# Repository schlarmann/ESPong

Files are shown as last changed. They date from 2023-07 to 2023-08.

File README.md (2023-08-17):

# ESPong
PCB / Code for the ESP8266 Pong game. Based on the ESP Channel3 library

## File structure
 - pongCard: KiCad project for the pcb. Currently in Version 3
 - channel3Pong: Source code for ESPong itself. Code needs to refactored, it was written with / for cnlohr's SDK and then simply ported over to the arduino library.
 - channel3Image: Displays a static Image (Makerspace Minden logo). Comes with a converter script to convert pngs to header files.
 - channel3EtchASketch: Simple Etch-A-Sketch implementation for the pongCard. Demo board has rotating potentiometers instead of linear ones. Results are still "dotty" and there is no reset button to clear the screen

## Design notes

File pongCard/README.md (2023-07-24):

# Pong card
PCB for ESPong3D

## BOM
| Reference | Qty | Value | Link | 
|---|-----|---|---|
| BT1, BT2 | 2 | AAA | https://www.lcsc.com/product-detail/Battery-Connectors_MYOUNG-BH-AAA-A1AJ001_C5290189.html |
| C1, C3, C8 | 3 | 100u | https://www.lcsc.com/product-detail/Multilayer-Ceramic-Capacitors-MLCC-SMD-SMT_Samsung-Electro-Mechanics-CL31A107MQHNNNE_C15008.html |
| C4, C9, C2 | 2 | 100n | https://www.lcsc.com/product-detail/Multilayer-Ceramic-Capacitors-MLCC-SMD-SMT_Walsin-Tech-Corp-0603B104K250CT_C83054.html |
| C5, C6 | 2 | 22p |  |
| C7 | 1 | 100p |  |
| D1 | 1 | 1N5819 | https://www.lcsc.com/product-detail/Schottky-Barrier-Diodes-SBD_HXY-MOSFET-1N5819W_C5451628.html |
| J1 | 1 | USB_B_Micro | https://www.lcsc.com/product-detail/USB-Connectors_SHOU-HAN-MicroXNJ_C404969.html |
| L1 | 1 | 47µ | https://www.lcsc.com/product-detail/Inductors-SMD_Sunlord-AWL3225FP470MTF_C2846230.html |
| R1, R2, R3, R4, R5 | 5 | 22k | https://www.lcsc.com/product-detail/Chip-Resistor-Surface-Mount_RALEC-RTT03223JTP_C103426.html |
| R6 | 1 | 47R |  |
| RV1, RV2 | 2 | 10k // 100k | https://www.lcsc.com/product-detail/Variable-Resistors-Potentiometers_ALPSALPINE-RS30H11AA009_C470610.html(or: https://www.pollin.de/p/schieberegler-30ld1c-b-cap5-100k-240836) |
| SW1 | 1 | SW_SPDT_COM | https://www.lcsc.com/product-detail/Slide-Switches_SHOU-HAN-MSK12C02-HB_C431541.html |
| U2 | 1 | HT7533-1-SOT89 | https://lcsc.com/product-detail/Linear-Voltage-Regulators-LDO_KEXIN-HT7533_C499633.html |
| U3 | 1 | ESP-12E | https://www.lcsc.com/product-detail/WiFi-Modules_Ai-Thinker-ESP-12F-ESP8266MOD_C82891.html |
| U4 | 1 | QX2303L33E | https://www.lcsc.com/product-detail/DC-DC-Converters_QX-Micro-Devices-QX2303L33E_C236071.html |

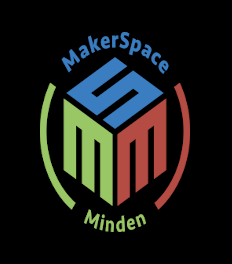
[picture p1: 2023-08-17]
channel3Image/convert/image.png

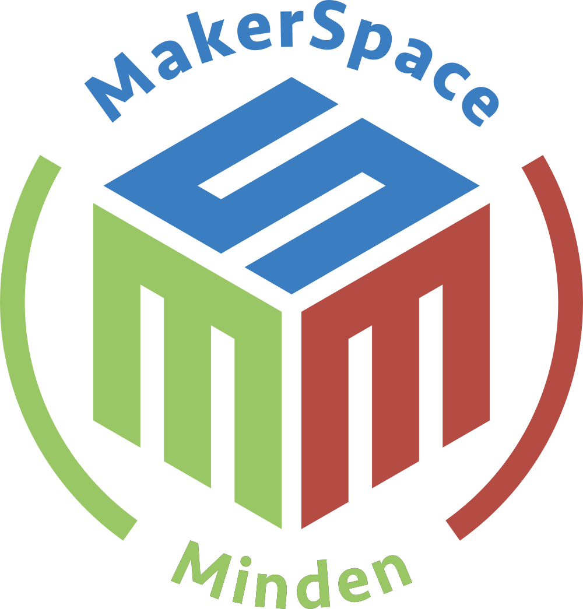
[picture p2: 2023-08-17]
channel3Image/convert/image_raw.png

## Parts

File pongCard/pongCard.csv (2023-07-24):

# | Reference | Qty | Value | Footprint | DNP
1 | BT1, BT2 | 2 | AAA | pongCard:BatteryHolder_AAA_MYOUNG
2 | C1, C3, C8 | 3 | 100u | Capacitor_SMD:C_1206_3216Metric_Pad1.33x1.80mm_HandSolder
3 | C2 | 1 | 100nF | Capacitor_SMD:C_0603_1608Metric_Pad1.08x0.95mm_HandSolder
4 | C4, C9 | 2 | 100n | Capacitor_SMD:C_0603_1608Metric_Pad1.08x0.95mm_HandSolder
5 | C5, C6 | 2 | 22p | Capacitor_SMD:C_0603_1608Metric_Pad1.08x0.95mm_HandSolder
6 | C7 | 1 | 100p | Capacitor_SMD:C_0603_1608Metric_Pad1.08x0.95mm_HandSolder
7 | D1 | 1 | 1N5819 | Diode_SMD:D_SOD-123
8 | J1 | 1 | USB_B_Micro | Connector_USB:USB_Micro-B_Molex-105017-0001
9 | J2, J3 | 2 | Conn_02x04_Odd_Even | pongCard:protoPins2x4
10 | JP1, JP2, JP3, JP4 | 4 | Jumper_2_Open | Jumper:SolderJumper-2_P1.3mm_Open_RoundedPad1.0x1.5mm
11 | L1 | 1 | 47µ | Inductor_SMD:L_1210_3225Metric_Pad1.42x2.65mm_HandSolder
12 | R1, R2, R3, R4, R5 | 5 | 22k | Resistor_SMD:R_0603_1608Metric_Pad0.98x0.95mm_HandSolder
13 | R6 | 1 | 47R | Resistor_SMD:R_0603_1608Metric_Pad0.98x0.95mm_HandSolder
14 | RV1, RV2 | 2 | 10k // 100k | pongCard:linearPotentiometer
15 | SW1 | 1 | SW_SPDT_COM | pongCard:SW_SPDT_PCM12_COM
16 | U1 | 1 | ESP-01v090 | pongCard:ESP-01
17 | U2 | 1 | HT75xx-1-SOT89 | Package_TO_SOT_SMD:SOT-89-3_Handsoldering
18 | U3 | 1 | ESP-12E | ESP8266:ESP-12E
19 | U4 | 1 | QX2303L33E | Package_TO_SOT_SMD:SOT-89-3_Handsoldering

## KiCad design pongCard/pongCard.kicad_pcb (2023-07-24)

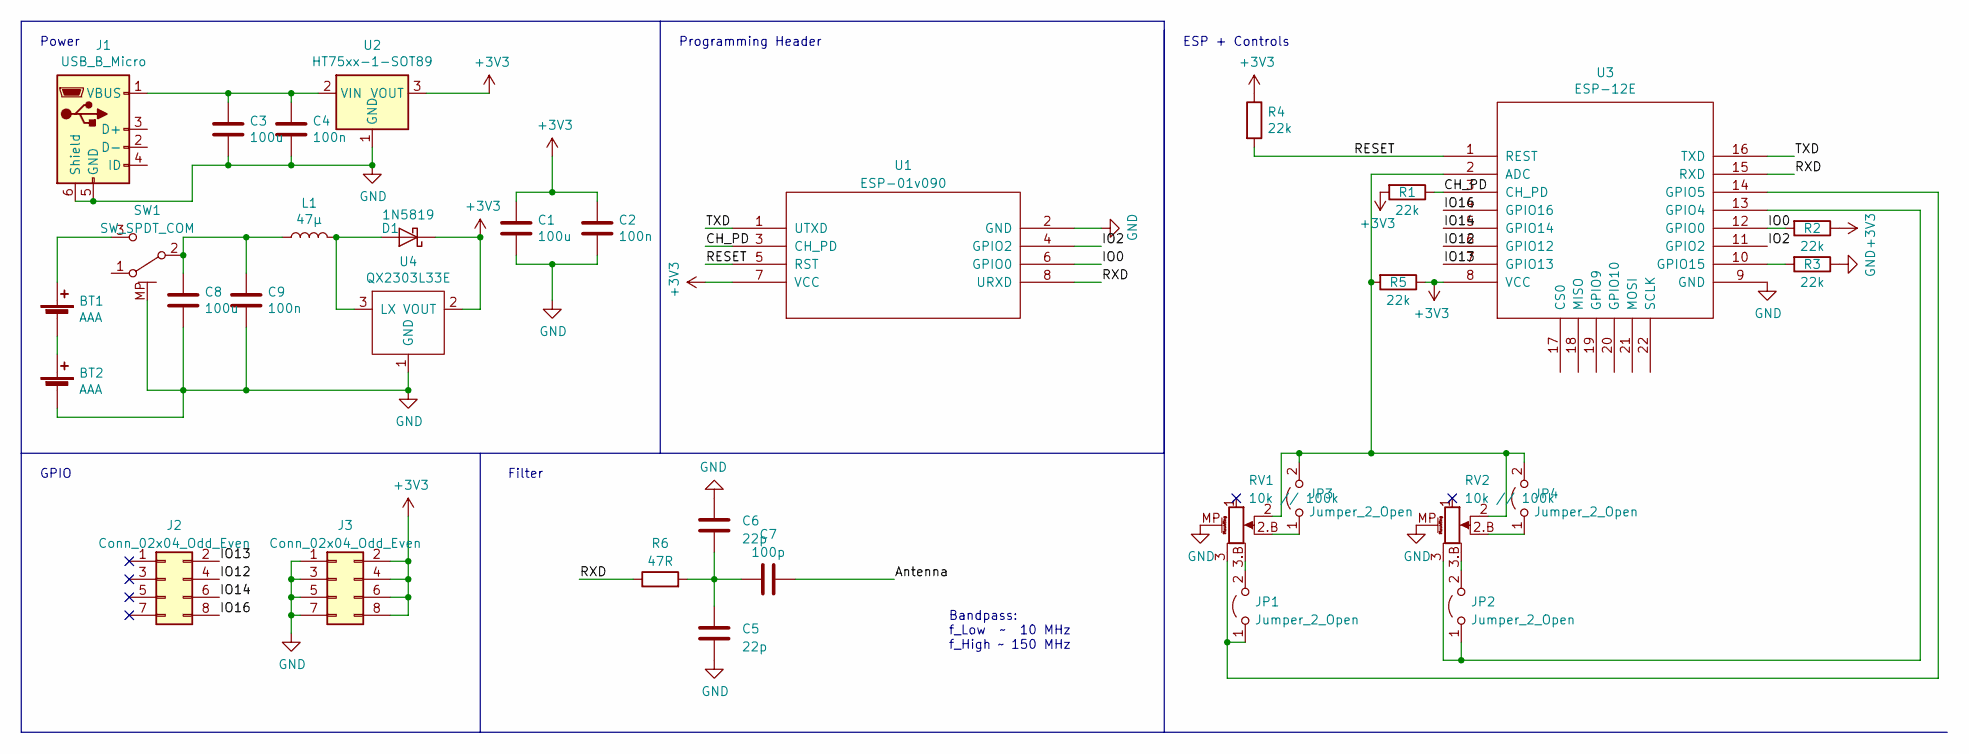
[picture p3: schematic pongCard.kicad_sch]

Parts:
BT1, BT2: AAA; BatteryHolder_AAA_MYOUNG
C1, C3, C8: 100u; C_1206_3216Metric_Pad1.33x1.80mm_HandSolder
C2, C4, C9: 100n; C_0603_1608Metric_Pad1.08x0.95mm_HandSolder
C5, C6: 22p; C_0603_1608Metric_Pad1.08x0.95mm_HandSolder
C7: 100p; C_0603_1608Metric_Pad1.08x0.95mm_HandSolder
D1: 1N5819; D_SOD-123
J1: USB_B_Micro; USB_Micro-B_Molex-105017-0001
J2, J3: Conn_02x04_Odd_Even; protoPins2x4
JP1, JP2, JP3, JP4: Jumper_2_Open; SolderJumper-2_P1.3mm_Open_RoundedPad1.0x1.5mm
L1: 47µ; L_1210_3225Metric_Pad1.42x2.65mm_HandSolder
R1, R2, R3, R4, R5: 22k; R_0603_1608Metric_Pad0.98x0.95mm_HandSolder
R6: 47R; R_0603_1608Metric_Pad0.98x0.95mm_HandSolder
RV1, RV2: 10k // 100k; linearPotentiometer
SW1: SW_SPDT_COM; SW_SPDT_PCM12_COM
U1: ESP-01v090; ESP-01
U2: HT75xx-1-SOT89; SOT-89-3_Handsoldering
U3: ESP-12E
U4: QX2303L33E; SOT-89-3_Handsoldering

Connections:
+3V3: C1.1, C2.1, D1.1 (K), J3.2, J3.4, J3.6, J3.8, R1.2, R2.1, R4.1, R5.1, U1.7 (VCC), U2.3 (VOUT), U3.8 (VCC), U4.2 (VOUT)
/Antenna: C7.2
/CH_PD: R1.1, U1.3 (CH_PD), U3.3 (CH_PD)
/IO0: R2.2, U1.6 (GPIO0), U3.12 (GPIO0)
/IO2: U1.4 (GPIO2), U3.11 (GPIO2)
/IO12: J2.4, U3.6 (GPIO12)
/IO13: J2.2, U3.7 (GPIO13)
/IO14: J2.6, U3.5 (GPIO14)
/IO16: J2.8, U3.4 (GPIO16)
/RESET: R4.2, U1.5 (RST), U3.1 (REST)
/RXD: R6.1, U1.8 (URXD), U3.15 (RXD)
/TXD: U1.1 (UTXD), U3.16 (TXD)
GND: BT2.2 (-), C1.2, C2.2, C3.2, C4.2, C5.2, C6.1, C8.2, C9.2, J1.5 (GND), J1.6 (Shield), J3.1, J3.3, J3.5, J3.7, R3.1, RV1.MP (MountPin), RV2.MP (MountPin), SW1.MP, U1.2 (GND), U2.1 (GND), U3.9 (GND), U4.1 (GND)
unnamed: BT1.1 (+), SW1.3 (C)
unnamed: BT1.2 (-), BT2.1 (+)
unnamed: C5.1, C6.2, C7.1, R6.2
unnamed: D1.2 (A), L1.2, U4.3 (LX)
unnamed: C3.1, C4.1, J1.1 (VBUS), U2.2 (VIN)
unnamed: JP1.1 (A), RV1.3, U3.14 (GPIO5)
unnamed: JP1.2 (B), RV1.3.B
unnamed: JP2.1 (A), RV2.3, U3.13 (GPIO4)
unnamed: JP2.2 (B), RV2.3.B
unnamed: JP3.1 (A), RV1.2.B
unnamed: JP3.2 (B), JP4.2 (B), R5.2, RV1.2, RV2.2, U3.2 (ADC)
unnamed: JP4.1 (A), RV2.2.B
unnamed: C8.1, C9.1, L1.1, SW1.2 (B)
unnamed: R3.2, U3.10 (GPIO15)

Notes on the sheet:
GPIO
Bandpass: f_Low ~ 10 MHz f_High ~ 150 MHz
Programming Header
Filter
ESP + Controls
Power

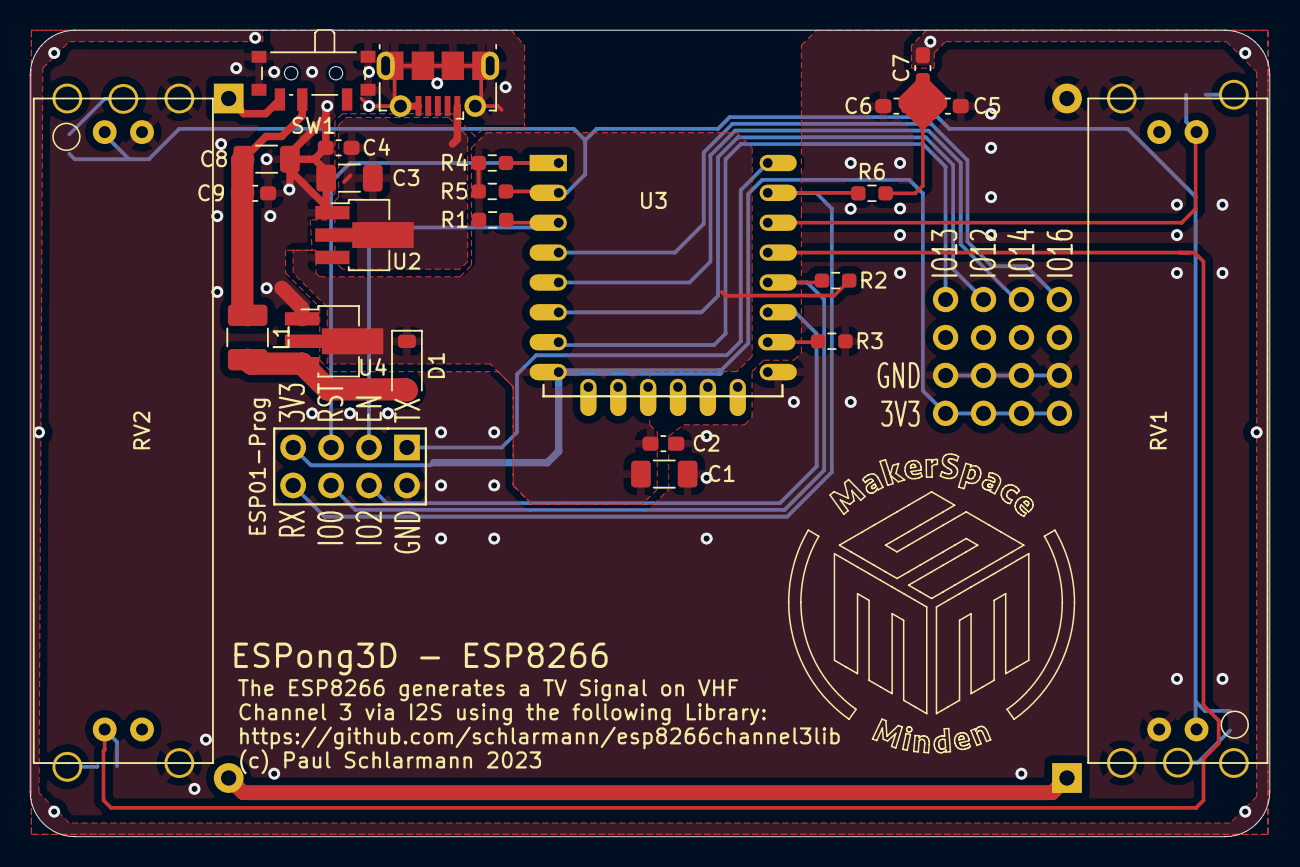
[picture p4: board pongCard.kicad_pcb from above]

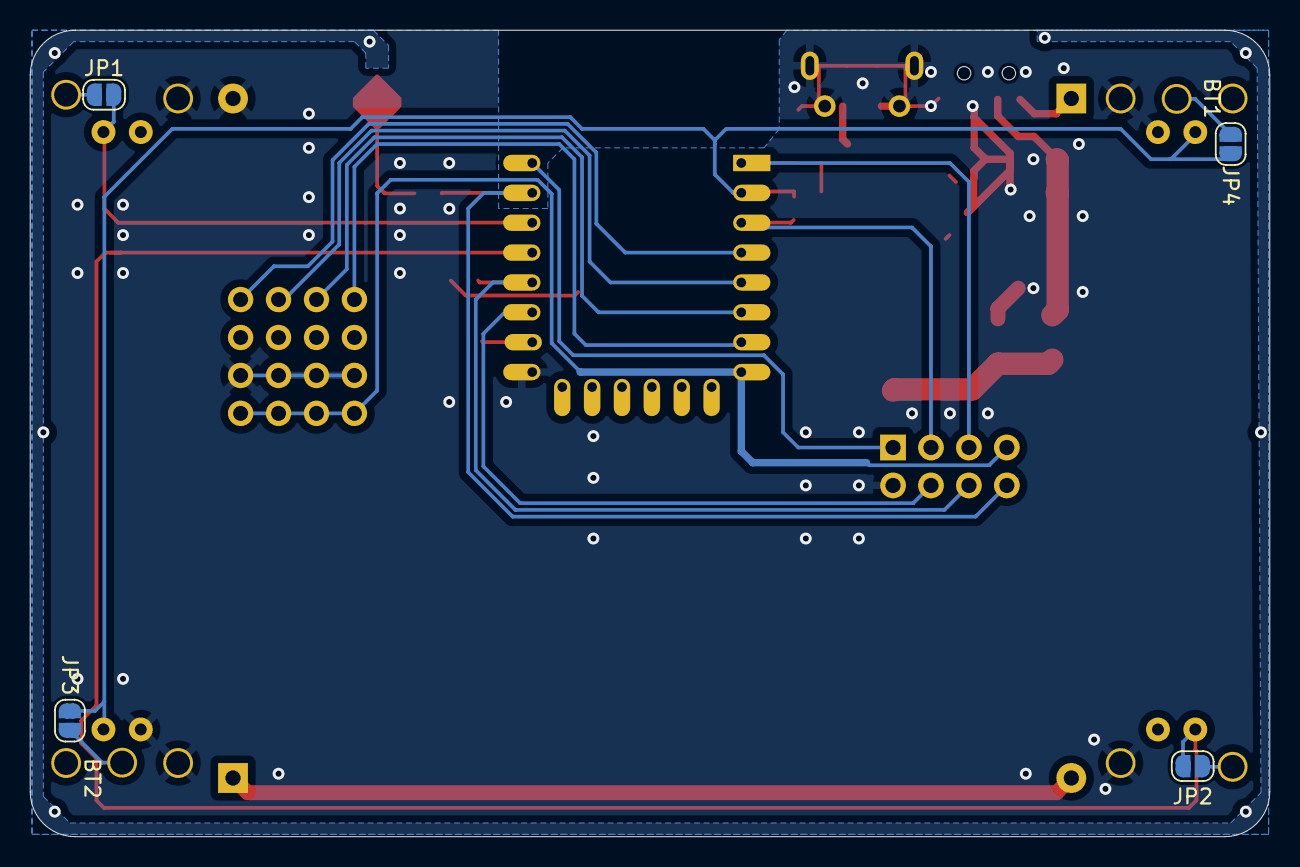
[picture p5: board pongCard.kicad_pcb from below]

Board: 2 copper layers, 83.0 x 54.0 mm, 34 parts (6 on the bottom side), 26 nets.

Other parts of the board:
LogoCu**: LogoCu

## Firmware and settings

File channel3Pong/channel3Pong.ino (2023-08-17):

#include <ESP8266WiFi.h>
#include <ArduinoOTA.h>


#include <esp8266channel3lib.h>
#include "pong_geometry.h"

#define POTI_L_PIN 4
#define POTI_R_PIN 5
int16_t paddlePos[2] = {0,0};

#define MAX_SCORE 10
int scorePaddle[2] = {0,0};

#define ADCVAL_TO_Y_POS(ADC) ((ADC)/6.4f)
int adcIdx = 0;

float ballTotalVel = 2.0f;

float ballPosX = 0;
float ballPosY = 0;
float ballVelX = 1;
float ballVelY = 2;
uint32_t frameCount = 0;
uint8_t showallowadvance = 1;
int framessostate = 0;
int framestempcount = 0;
int showtemp = 0;

void SetupMatrix( )
{
  int16_t lmatrix[16];
  tdIdentity( ProjectionMatrix );
  tdIdentity( ModelviewMatrix );

  Perspective( 600, 250, 50, 8192, ProjectionMatrix );
}

void Draw3DSegmentTranslate( int16_t * c1, int16_t * c2, int dx, int dy)
{
  int16_t sx0, sy0, sx1, sy1;
  LocalToScreenspace( c1, &sx0, &sy0 );
  LocalToScreenspace( c2, &sx1, &sy1 );
  CNFGTackSegment( sx0+dx, sy0+dy, sx1+dx, sy1+dy );
}

void Draw3DModelTranslate(int16_t *verts, uint16_t *indices, int lenIndices, int dx,int dy){
  int i;
  int nrv = lenIndices/sizeof(uint16_t);
  for( i = 0; i < nrv; i+=2 )
  {
    int16_t * c1 = &verts[indices[i]];
    int16_t * c2 = &verts[indices[i+1]];
    Draw3DSegmentTranslate( c1, c2, dx,dy );
  }
}

void LeftPaddle(int posy){
  int16_t ftmp[16];
  memcpy(ftmp, ModelviewMatrix, sizeof(ModelviewMatrix));
  MakeTranslate(PADDLE_CENTER_X(138),PADDLE_CENTER_Y(0),512, ModelviewMatrix);
  ModelviewMatrix[0] = PADDLE_X;
  ModelviewMatrix[5] = PADDLE_Y;
  ModelviewMatrix[10] = PADDLE_Z;
  Draw3DModelTranslate(cubeVerts, cubeIndices, sizeof(cubeIndices) ,-64,posy+1);
  memcpy(ModelviewMatrix, ftmp, sizeof(ModelviewMatrix));
}


void RightPaddle(int posy){
  int16_t ftmp[16];
  memcpy(ftmp, ModelviewMatrix, sizeof(ModelviewMatrix));
  MakeTranslate(PADDLE_CENTER_X(-138),PADDLE_CENTER_Y(0),512, ModelviewMatrix);
  ModelviewMatrix[0] = PADDLE_X;
  ModelviewMatrix[5] = PADDLE_Y;
  ModelviewMatrix[10] = PADDLE_Z;
  Draw3DModelTranslate(cubeVerts, cubeIndices, sizeof(cubeIndices) ,64,posy+1);
  memcpy(ModelviewMatrix, ftmp, sizeof(ModelviewMatrix));
}

void Outline(){
  CNFGColor( 5 );
  int16_t ftmp[16];
  memcpy(ftmp, ModelviewMatrix, sizeof(ModelviewMatrix));
  MakeTranslate(-460,-425,512, ModelviewMatrix);
  ModelviewMatrix[0] = 920;
  ModelviewMatrix[5] = 850;
  ModelviewMatrix[10] = 200;
  Draw3DModelTranslate(cubeVerts, cubeIndices, sizeof(cubeIndices) ,0,0);
  memcpy(ModelviewMatrix, ftmp, sizeof(ModelviewMatrix));
  CNFGColor( 17 );
}

void Ball(){
  int16_t ftmp[16];
  memcpy(ftmp, ModelviewMatrix, sizeof(ModelviewMatrix));
  tdIdentity( ModelviewMatrix );
  tdScale(ModelviewMatrix, BALL_X, BALL_Y, BALL_Z);
  tdRotateEA(ModelviewMatrix, framessostate*3,framessostate*5,2*framessostate);
  ModelviewMatrix[11] = 768;
  ModelviewMatrix[3] = BALL_CENTER_X(0);
  ModelviewMatrix[7] = BALL_CENTER_Y(0);
  Draw3DModelTranslate(dodecahedronVerts, dodecahedronIndices, sizeof(dodecahedronIndices) ,((int)ballPosX)-5,((int)ballPosY)-5);
  memcpy(ModelviewMatrix, ftmp, sizeof(ModelviewMatrix));
}

int calcPaddlePos(uint16_t adcVal){
  /*
  if(adcVal<50)
    return -70;
  if(adcVal>450)
    return 70;

  return ((adcVal-50)/2.9f)-70;
  */

  if(adcVal < 50)
    return -70;
  if(adcVal > 975)
    return 70;

  return (adcVal-512)/7.4;
}

void resetBall(){
  ballPosX = 0;
  ballPosY = 0;
  ballVelX = (os_random() & 1)? -ballTotalVel:ballTotalVel;
  ballVelY = (tdSIN(os_random())/256.0f) * ballTotalVel;
}

void calcNewBallPos(){
  ballPosX += ballVelX;
  ballPosY += ballVelY;
  if(ballPosY < BALL_Y_POS_MIN || ballPosY > BALL_Y_POS_MAX){
    ballVelY = -ballVelY;
  }

  if(ballPosX < BALL_X_POS_PADDLE_MIN){
    int ballYDelta = (paddlePos[0]-ballPosY);
    if(ballYDelta <= 0 && ballYDelta >= -PADDLE_RADIUS){
      ballVelX = -ballVelX;
      ballVelY = (tdSIN(3*ballYDelta)/256.0f) * ballTotalVel;
      ballPosX = BALL_X_POS_PADDLE_MIN;
    } else if(ballYDelta > 0 && ballYDelta < PADDLE_RADIUS){
      ballVelX = -ballVelX;
      ballVelY = -(tdSIN(3*ballYDelta)/256.0f) * ballTotalVel;
      ballPosX = BALL_X_POS_PADDLE_MIN;
    } 
  } 
  if (ballPosX < BALL_X_POS_MIN){
      scorePaddle[1]+=1;
      resetBall();
  } 

  if (ballPosX > BALL_X_POS_PADDLE_MAX){
    int ballYDelta = (paddlePos[1]-ballPosY);
    if(ballYDelta <= 0 && ballYDelta >= -PADDLE_RADIUS){
      ballVelX = -ballVelX;
      ballVelY = (tdSIN(3*ballYDelta)/256.0f) * ballTotalVel;
      ballPosX = BALL_X_POS_PADDLE_MAX;
    } else if(ballYDelta > 0 && ballYDelta < PADDLE_RADIUS){
      ballVelX = -ballVelX;
      ballVelY = -(tdSIN(3*ballYDelta)/256.0f) * ballTotalVel;
      ballPosX = BALL_X_POS_PADDLE_MAX;
    }
  } 
  if (ballPosX > BALL_X_POS_MAX){
      scorePaddle[0]+=1;
      resetBall();
  } 
}

int16_t Height( int x, int y, int l )
{
  return tdCOS( (x*x + y*y) + l );
}

// This callback gets called automatically every frame
void loadFrame()
{
    video_broadcast_clear_frame();
    CNFGPenX = 14;
    CNFGPenY = 20;
    int16_t rt[16];
    tdIdentity( ModelviewMatrix );
    tdIdentity( ProjectionMatrix );
    CNFGColor( 17 );

    
    adcIdx = (!adcIdx) & 1;
    if(adcIdx){
      pinMode(POTI_L_PIN, INPUT);
      pinMode(POTI_R_PIN, OUTPUT);
      digitalWrite(POTI_R_PIN, LOW);
    } else {
      pinMode(POTI_R_PIN, INPUT);
      pinMode(POTI_L_PIN, OUTPUT);
      digitalWrite(POTI_L_PIN, LOW);
    }
    
  
    if(scorePaddle[0] >= MAX_SCORE || scorePaddle[1] >= MAX_SCORE){
      // Show win screen
      if(framestempcount == 0)
        framestempcount = framessostate;
      CNFGColor( 17 );
      CNFGTackRectangle( 70, 110, 180+200, 150 );   
      CNFGColor( 16 );
      CNFGPenY += 14*6+10;
      CNFGPenX += 25;
      char buf[256];
      ets_sprintf(buf, "Player %c has won!", (scorePaddle[0] >= MAX_SCORE)?'1':'2' );
      CNFGDrawText(buf, 3);
      CNFGPenY += 16;
      CNFGPenX += 25;
      ets_sprintf(buf, "Score: %d:%d", scorePaddle[0], scorePaddle[1]);
      CNFGDrawText(buf, 3);
  
      if(framessostate-framestempcount == 5*25){
        scorePaddle[0] = 0;
        scorePaddle[1] = 0;
        resetBall();
        framestempcount = 0;
      }
    } else {
      // Game logic
      CNFGPenY += 24;
      CNFGPenX += 80;
      char buf[256];
      ets_sprintf(buf, "%d:%d", scorePaddle[0], scorePaddle[1]);
      CNFGDrawText(buf, 4);
  
      SetupMatrix();
      if(adcIdx)
        paddlePos[adcIdx] = calcPaddlePos(analogRead(A0));
      else 
        paddlePos[adcIdx] = calcPaddlePos(1024-analogRead(A0));
      Outline();
      LeftPaddle(paddlePos[0]);
      RightPaddle(paddlePos[1]);
      calcNewBallPos();
      Ball();
    }
    framessostate++;
}

void setup() {
  system_update_cpu_freq( SYS_CPU_160MHZ );
  Serial.begin(115200);
  Serial.println("Starting ESPong3D!");
  WiFi.softAP("ESPong3D", "ESPong3D");

  // Port defaults to 8266
  ArduinoOTA.setPort(8266);
  // Hostname defaults to esp8266-[ChipID]
  ArduinoOTA.setHostname("ESPong3D");

  ArduinoOTA.onStart([]() {
    channel3Deinit();
    String type;
    if (ArduinoOTA.getCommand() == U_FLASH) {
      type = "sketch";
    } else { // U_FS
      type = "filesystem";
    }
    Serial.println("Start updating " + type);
  });
  ArduinoOTA.onEnd([]() {   
    Serial.println("\nEnd");
  });
  ArduinoOTA.onProgress([](unsigned int progress, unsigned int total) {    
    Serial.printf("Progress: %u%%\r\n", (progress / (total / 100)));
  });
  ArduinoOTA.onError([](ota_error_t error) {
    
    Serial.printf("Error[%u]: ", error);
    if (error == OTA_AUTH_ERROR) {
      Serial.println("Auth Failed");
    } else if (error == OTA_BEGIN_ERROR) {
      Serial.println("Begin Failed");
    } else if (error == OTA_CONNECT_ERROR) {
      Serial.println("Connect Failed");
    } else if (error == OTA_RECEIVE_ERROR) {
      Serial.println("Receive Failed");
    } else if (error == OTA_END_ERROR) {
      Serial.println("End Failed");
    }
  });
  ArduinoOTA.begin();
  
  channel3Init(PAL, &loadFrame);
  Serial.printf("Update via %s:8266\n", WiFi.softAPIP().toString().c_str());
}

void loop() {
  // put your main code here, to run repeatedly:
  // Handle OTA requests
  ArduinoOTA.handle();
}

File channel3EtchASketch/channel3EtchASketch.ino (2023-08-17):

#include <ESP8266WiFi.h>
#include <ArduinoOTA.h>
#include <esp8266channel3lib.h>

// Value of potentiometer in kOhms (e.g. 10.0 or 100.0)
#define POT_MAX_KOHM 1024.0f

#define POT_L_PIN 4
#define POT_R_PIN 5

#define POT_L_IDX 0
#define POT_R_IDX 1

#define ANALOG_SAMPLES 50
uint32_t currentPotLIdx = 0;
uint32_t currentPotRIdx = 0;
uint32_t currentPotIdx = POT_L_IDX;
float potValueL[ANALOG_SAMPLES] = {0};
float potValueR[ANALOG_SAMPLES] = {0};

void gatherPotValues(){
  int value = 0;
  if(currentPotIdx == POT_L_IDX){
    pinMode(POT_R_PIN, INPUT);
    pinMode(POT_L_PIN, OUTPUT);
    digitalWrite(POT_L_PIN, LOW);

    delay(1);

    value=analogRead(A0); // Left potentiometer is mounted in "reverse"
    potValueL[currentPotLIdx] = value;
    currentPotLIdx++;
    if(currentPotLIdx >= ANALOG_SAMPLES)
      currentPotLIdx=0;
    
  } else {
    pinMode(POT_L_PIN, INPUT);
    pinMode(POT_R_PIN, OUTPUT);
    digitalWrite(POT_R_PIN, LOW);
    
    delay(1);
    
    value=analogRead(A0);
    potValueR[currentPotRIdx] = value;
    currentPotRIdx++;
    if(currentPotRIdx >= ANALOG_SAMPLES)
      currentPotRIdx=0;

  }

  if(currentPotIdx == POT_L_IDX){
    currentPotIdx = POT_R_IDX;
  } else {
    currentPotIdx = POT_L_IDX;
  }
  
}

float getPotValue(int idx){
  float avg = 0.0f;
  if(idx == POT_L_IDX){
    for(int i=0; i<ANALOG_SAMPLES; i++){
      avg += potValueL[i];
    }
  } else {
    for(int i=0; i<ANALOG_SAMPLES; i++){
      avg += potValueR[i];
    }
  }

  avg /= ANALOG_SAMPLES;

  return avg;
}

// This callback gets called automatically every frame
void loadFrame(){
  CNFGPenX = 25;
  CNFGPenY = 25;
  CNFGColor( 17 );
  CNFGDrawText("Etch-a-Sketch", 3);
  // Calculate position of cursor
  int xPos = video_broadcast_framebuffer_width()*(getPotValue(POT_L_IDX)/POT_MAX_KOHM); // Left/Right
  int yPos = video_broadcast_framebuffer_height()*(getPotValue(POT_R_IDX)/POT_MAX_KOHM); // Up/Down

  // Place white pixel
  video_broadcast_tack_pixel(xPos, yPos, C3_COL_DD_WHITE);
}

void setup() {
  system_update_cpu_freq( SYS_CPU_160MHZ );
  Serial.begin(115200);
  Serial.println("Starting ESP-EtchASketch!");
  WiFi.softAP("EtchaSketchP", "EtchaSketchP");

  // Port defaults to 8266
  ArduinoOTA.setPort(8266);
  // Hostname defaults to esp8266-[ChipID]
  ArduinoOTA.setHostname("EtchaSketchP");

  ArduinoOTA.onStart([]() {
    channel3Deinit();
    String type;
    if (ArduinoOTA.getCommand() == U_FLASH) {
      type = "sketch";
    } else { // U_FS
      type = "filesystem";
    }
    Serial.println("Start updating " + type);
  });
  ArduinoOTA.onEnd([]() {   
    Serial.println("\nEnd");
  });
  ArduinoOTA.onProgress([](unsigned int progress, unsigned int total) {    
    Serial.printf("Progress: %u%%\r\n", (progress / (total / 100)));
  });
  ArduinoOTA.onError([](ota_error_t error) {
    
    Serial.printf("Error[%u]: ", error);
    if (error == OTA_AUTH_ERROR) {
      Serial.println("Auth Failed");
    } else if (error == OTA_BEGIN_ERROR) {
      Serial.println("Begin Failed");
    } else if (error == OTA_CONNECT_ERROR) {
      Serial.println("Connect Failed");
    } else if (error == OTA_RECEIVE_ERROR) {
      Serial.println("Receive Failed");
    } else if (error == OTA_END_ERROR) {
      Serial.println("End Failed");
    }
  });
  ArduinoOTA.begin();
  
  channel3Init(PAL, &loadFrame);
  Serial.printf("Update via %s:8266\n", WiFi.softAPIP().toString().c_str());
}

void loop() {
  // put your main code here, to run repeatedly:
  // Handle OTA requests
  ArduinoOTA.handle();
  gatherPotValues();
}

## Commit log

2023-07-24 INIT: Added V2 (current SOP)
    [pongCard-B_Cu.gbl, pongCard-B_Mask.gbs, pongCard-B_Paste.gbp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]
2023-07-24 V3: Battery Step up
    [pongCard-B_Cu.gbl, pongCard-B_Mask.gbs, pongCard-B_Paste.gbp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]
